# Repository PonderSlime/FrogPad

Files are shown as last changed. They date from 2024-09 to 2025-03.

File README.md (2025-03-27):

# Frogpad
This is my design for Hack Club's Hackpad Challenge. It features a rotary encoder, 15 switches, and a charming froggy face.
<details>
<summary>

# Details
</summary>
<details>

<summary>

## The PCB
</summary>
The first step in my design was to create the pcb schematic.
This involved choosing what components to use and how they should be wired to each other. Overall, this was the easiest step in the design process, since
I am only using 15 switches and 1 rotary encoder.

The next step was for me to decide on a layout for my board.
I decided to go for an erginomic key layout. The encoder sits conveniently in a spot that could be considered a "nose." The macropad truly became a frog when
I decided that I wanted a unique outline and couldn't quite achieve what I was initally going for. During the case design, I was forced to relocate the SeeedStudio
XIAO RP2040 several times, to allow it to plug in better. I also modified the through-hole sizes several times for a similar reason: I needed the case to stay together.

I made many mistakes on the way of my project, and several times had to completely rebuild my case design. Although I encountered many setbacks, 
I still continued on. The hardest thing with designing the pcb was when I was forced to completely restart on the wire traces due to a slight layout change.
frogpad PCB

</details>
<details>
<summary>

## The Case

</summary>
For this step I decided to use Onshape. Since this was my first time using Onshape, this took longer than i had hoped for. Luckily, after learning the basics, it was pretty easy to design my case to fit my board. I'm really happy with how it turned out.
</details>
<details>
<summary>

## The Firmware
</summary>
In the past, i have mainly used python for my hardware projects (the only one to date being for bin.) However, in my mind, this project is more like professional design. Since this was the case, I decided to use a dedicated keyboard firmware tool: QMK. I struggled a lot on this step, since i couldn't immediatly find a good firmware base for the RP2040. In the end, I was able to finish the firmware succesfully, with support for the encoder and all 15 keys.
</details>
<details>
<summary>

## In Retrospect
</summary>

During the time spent designing my macropad, I learned more about how to use Kicad, Onshape and QMK. All of these tools were hard in there own way.

Kicad was difficult for me due to the unique board outline and drill hole sizes.

Onshape was tricky because it was my first time using 3D cad software other than Blender.

OMK was especially difficult due to lack of information on using a RP2040 microcontroller.# PonderSime-Hackpad
</details>

</details>

# Keymaps
### Layer 0
| ______ | Space | TO(2) | ______ | ______ |
| --- | --- | ---  | ---| ---|
| Q | W | E | R | T |
| A | S | D | F | G |
| Z | X | C | V | TD(0) |

### Layer 1
| ______ | Space | TO(2) | ______ | ______ |
| --- | --- | ---  | ---| ---|
| Y | U | I | O | P |
| H | J | K | L | . |
| B | N | M | , |  |

### Layer 2
| ______ | TO(0) | TO(3) | ______ | ______ |
| --- | --- | ---  | ---| ---|
| TD(2) | TD(3) | TD(4) | TD(5) | TD(6) |
| TD(7) | TD(8) | TD(9) | TD(10) | TD(11) |
| Left | Up | Down | Right | TD(1) |

### Layer 3
| ______ | TO(2) | Space | ______ | ______ |
| --- | --- | ---  | ---| ---|
| F1 | F2 | F3 | F4 | F5 |
| F6 | F7 | F8 | F9 | F10 |
| F11 | F12 | Esc | Tab |  |

## Tap-Dance Info
| Which One | On Tap | On Hold | Double Tap | Tap and Hold |
| --- | --- | --- | --- | --- |
| 0 | Space | MO(1) | Enter | Bksp | 
| 1 | Space | MO(3) | Enter | Bksp | 
| 2 | 1 |  | 6 |  | 
| 3 | 2 |  | 7 |  | 
| 4 | 3 |  | 8 |  | 
| 5 | 4 |  | 9 |  | 
| 6 | 5 |  | 0 |  | 
| 7 | - |  | = |  | 
| 8 | ' |  | ` |  | 
| 9 | [ |  | ] |  | 
| 10 | Esc |  | / |  | 
| 11 | \ |  | Caps |  |

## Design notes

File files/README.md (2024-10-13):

# Frogpad

# BOM:
- 15x Cherry MX switches (through hole)
- 15x 0805 (2012 metric) 1.5x1.40mm HandSolder Diodes (whatever one has specs closest to 1n4148 diodes)
- 1x Alps Alpine EC11E Switch Encoder
- 1x PCB
- 1x SeeedStudio XIAO RP2040 microcontroller

# 3D Prints
- 1x Case Top
- 1x Case Bottom
- 1x Rotary encoder cap (scaling is wrong for some reason, i dont need a massive encoder cap!)

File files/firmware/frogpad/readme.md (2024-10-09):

# frogpad

frogpad

*A short description of the keyboard/project*

* Keyboard Maintainer: [PonderSlime](https://github.com/PonderSlime)
* Hardware Supported: *The PCBs, controllers supported*
* Hardware Availability: *Links to where you can find this hardware*

Make example for this keyboard (after setting up your build environment):

    make frogpad:default

Flashing example for this keyboard:

    make frogpad:default:flash

See the [build environment setup](https://docs.qmk.fm/#/getting_started_build_tools) and the [make instructions](https://docs.qmk.fm/#/getting_started_make_guide) for more information. Brand new to QMK? Start with our [Complete Newbs Guide](https://docs.qmk.fm/#/newbs).

## Bootloader

Enter the bootloader in 3 ways:

* **Bootmagic reset**: Hold down the key at (0,0) in the matrix (usually the top left key or Escape) and plug in the keyboard
* **Physical reset button**: Briefly press the button on the back of the PCB - some may have pads you must short instead
* **Keycode in layout**: Press the key mapped to `QK_BOOT` if it is available

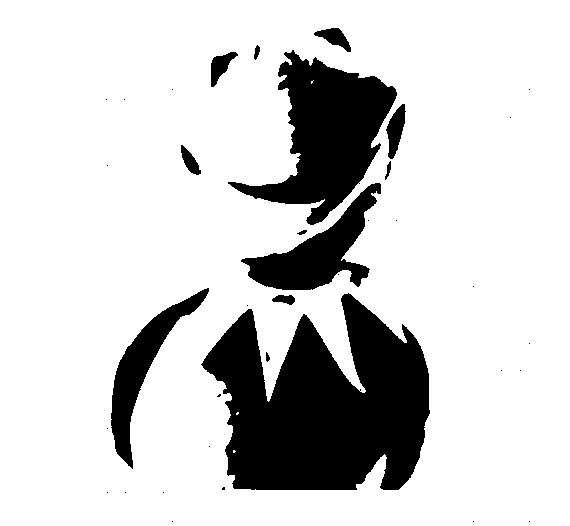
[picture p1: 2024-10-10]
files/pcb/decoration/kermit_sihlouette.png

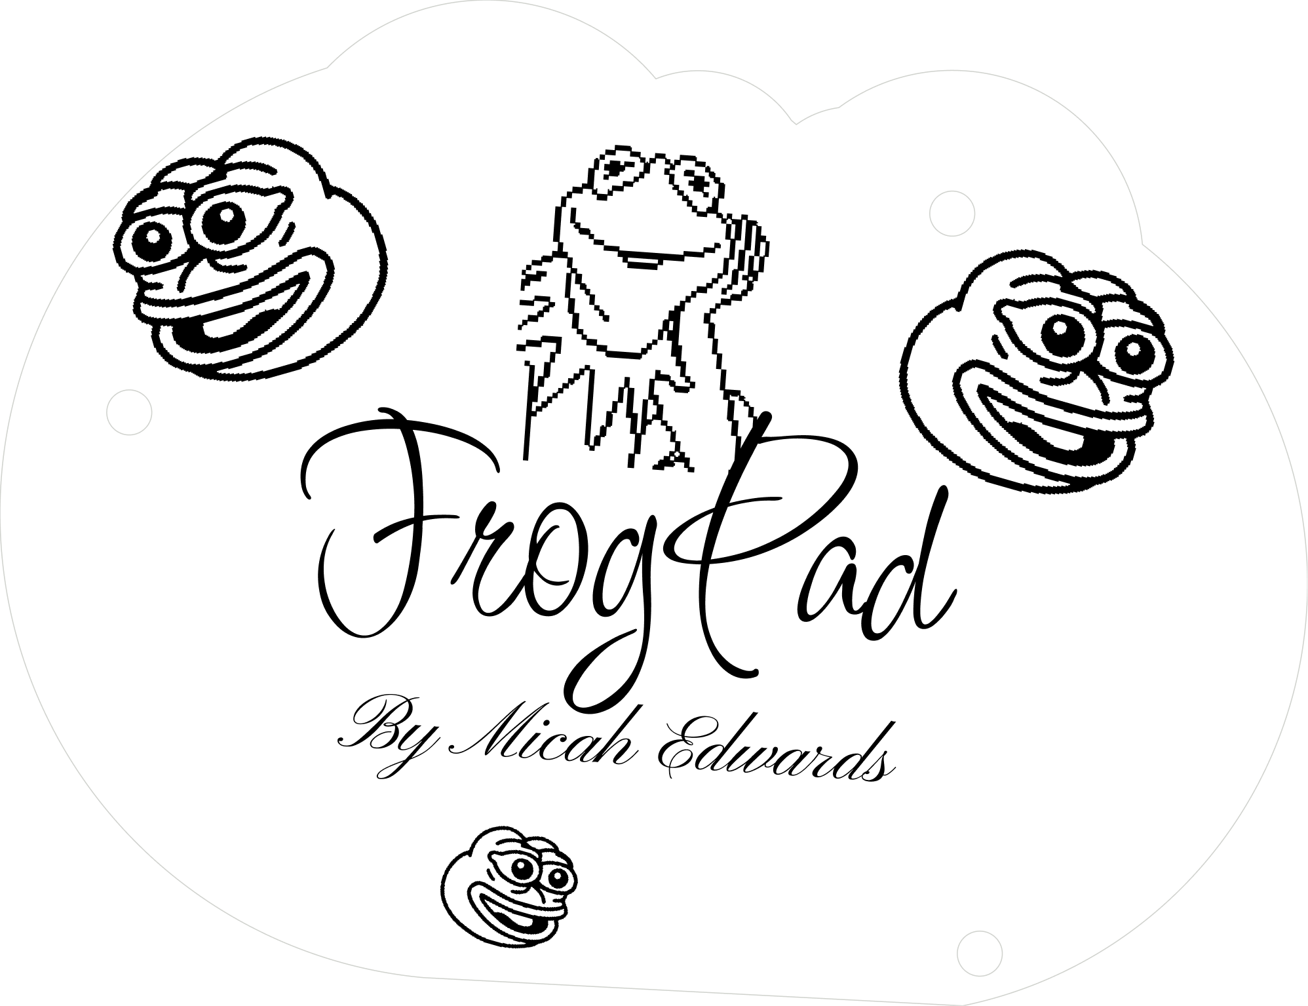
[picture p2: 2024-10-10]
files/pcb/decoration/Back.png

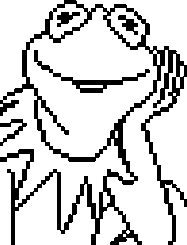
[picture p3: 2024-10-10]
files/pcb/decoration/kermit.png

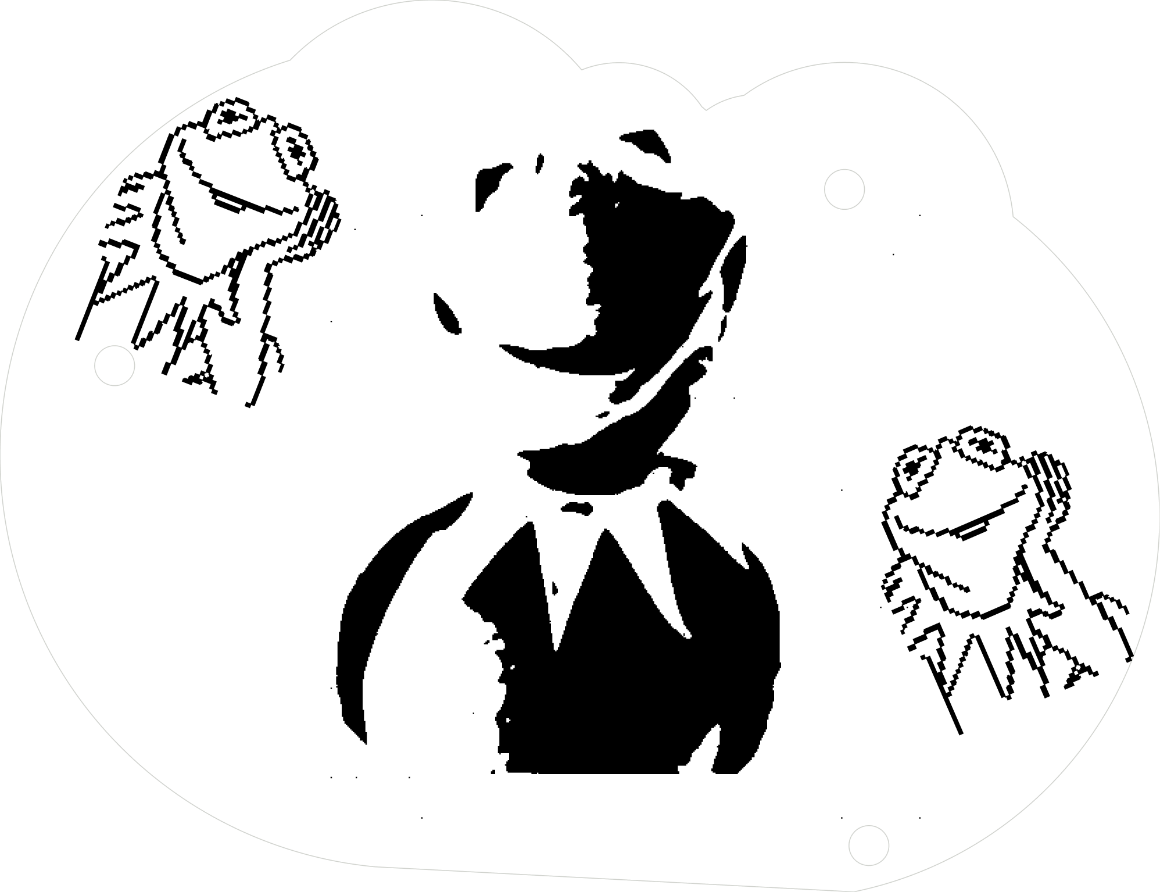
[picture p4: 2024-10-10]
files/pcb/decoration/Front.png

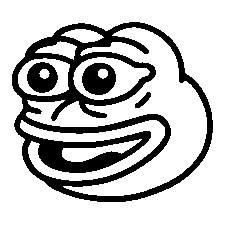
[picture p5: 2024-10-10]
files/pcb/decoration/Pepe.png

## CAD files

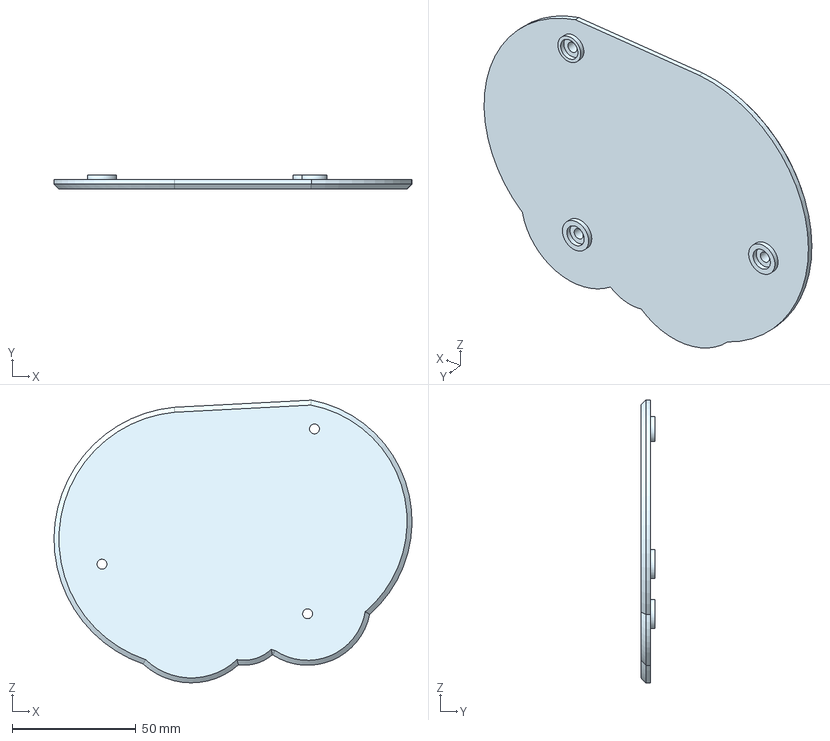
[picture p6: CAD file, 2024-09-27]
files/cad/3D Printed Parts/3D Printed Parts - Bottom Case Lid.step
144.7 x 5.80 x 114.2 mm

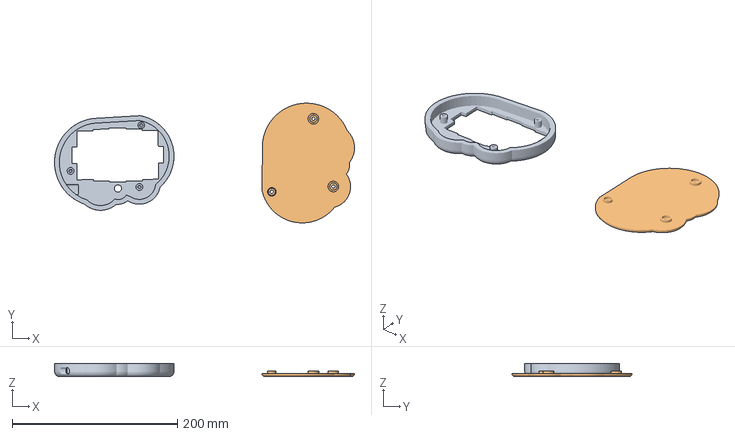
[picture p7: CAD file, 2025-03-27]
files/cad/Fixed 3D Models/Case - Bottom Case Lid.3mf
363.0 x 144.9 x 16.0 mm
Case - Case Top.stl
Case - Bottom Case Lid.stl

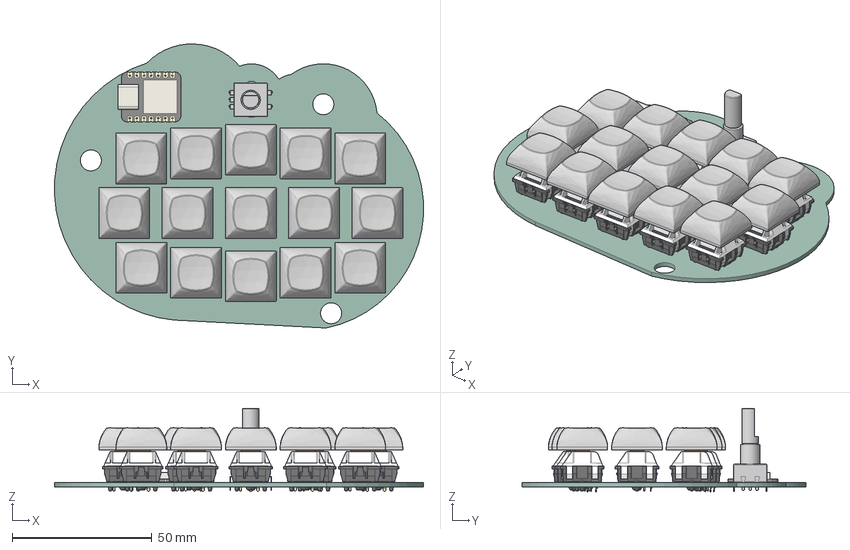
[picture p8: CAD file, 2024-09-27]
files/cad/hackpad_pcb_reference.step
131.9 x 101.5 x 29.8 mm
SW_Cherry_MX_PCB x 15
DSA V4 1x1 v4 x 15
Seeeduino Xiao v2
(Unsaved)
my_hackpad_PCB

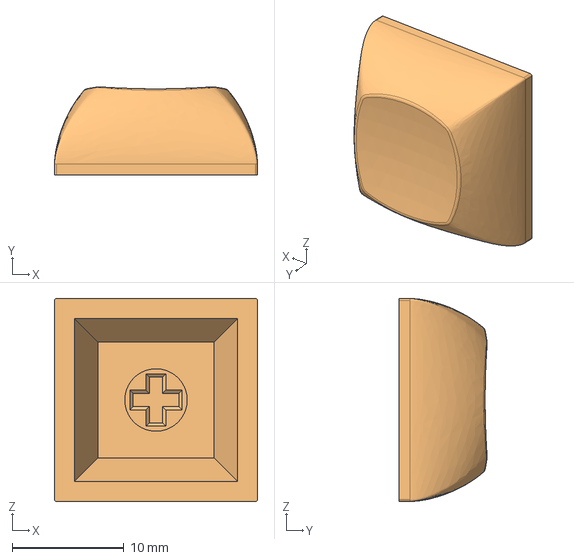
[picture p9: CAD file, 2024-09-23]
files/pcb/models/DSA 1u.step
18.2 x 7.91 x 18.2 mm

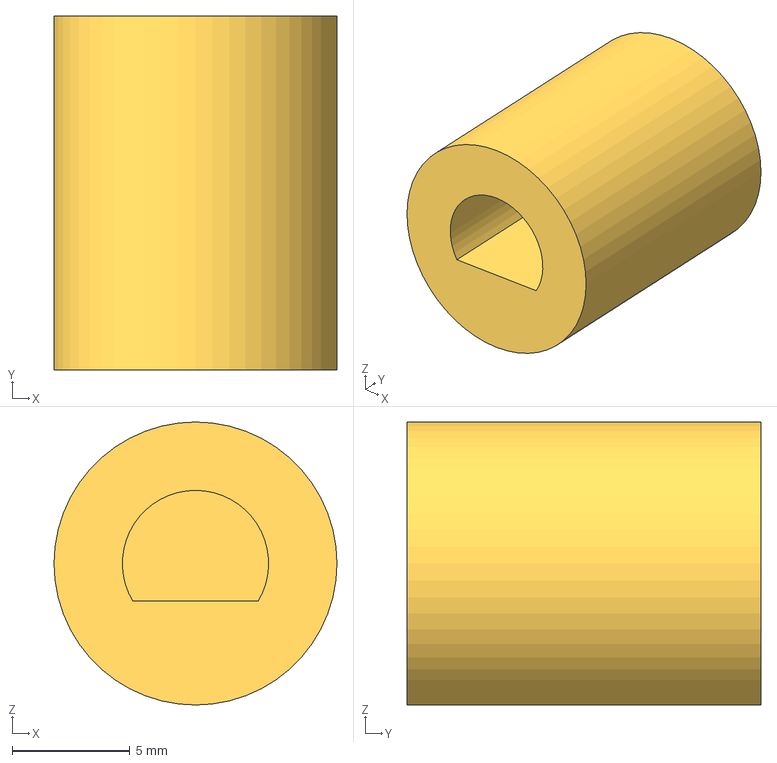
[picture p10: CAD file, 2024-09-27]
files/cad/3D Printed Parts/3D Printed Parts - Rotary Dial.step
12.0 x 15.0 x 12.0 mm

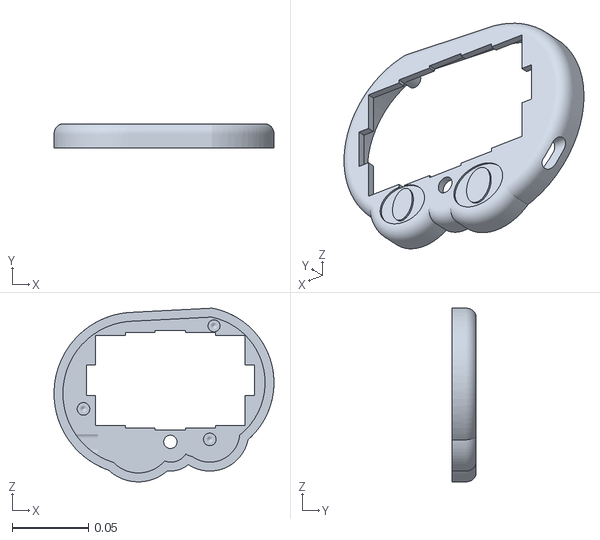
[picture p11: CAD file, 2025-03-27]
files/cad/Fixed 3D Models/Case - Case Top.stl
0.145 x 0.016 x 0.114

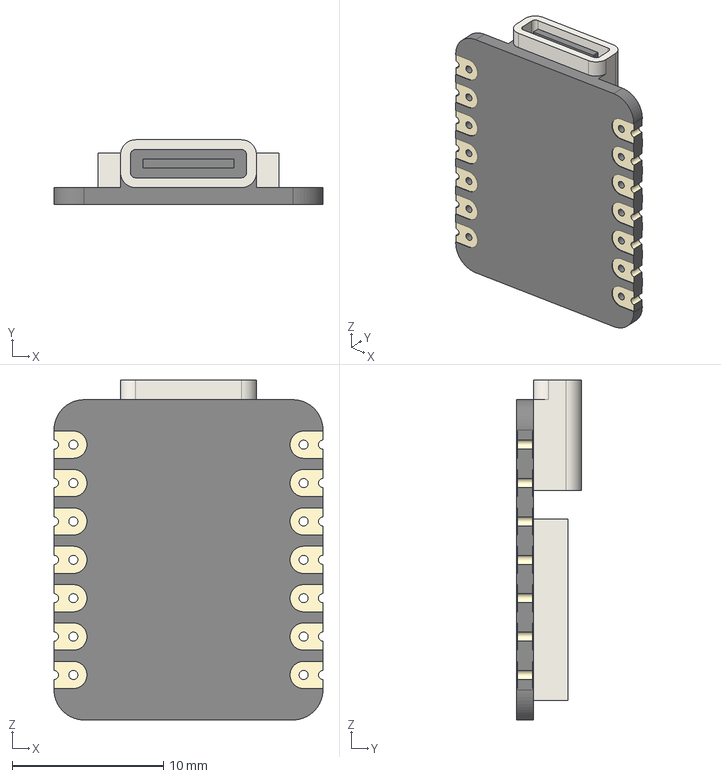
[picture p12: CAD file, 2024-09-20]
files/pcb/models/Seeeduino_Xiao.step
17.8 x 4.27 x 22.5 mm

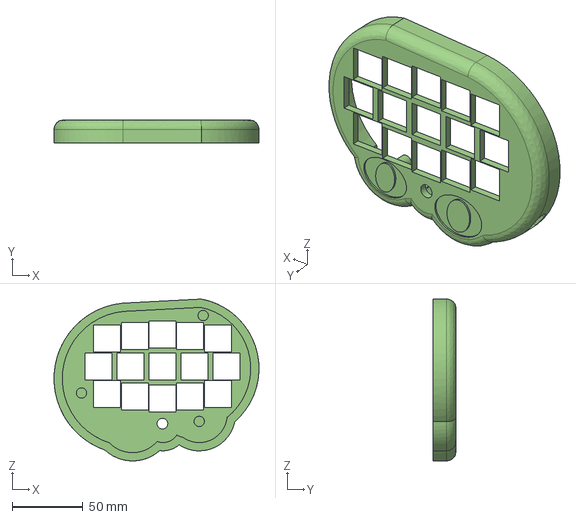
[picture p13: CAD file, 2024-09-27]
files/cad/3D Printed Parts/3D Printed Parts - Case Top.step
144.7 x 16.0 x 114.2 mm

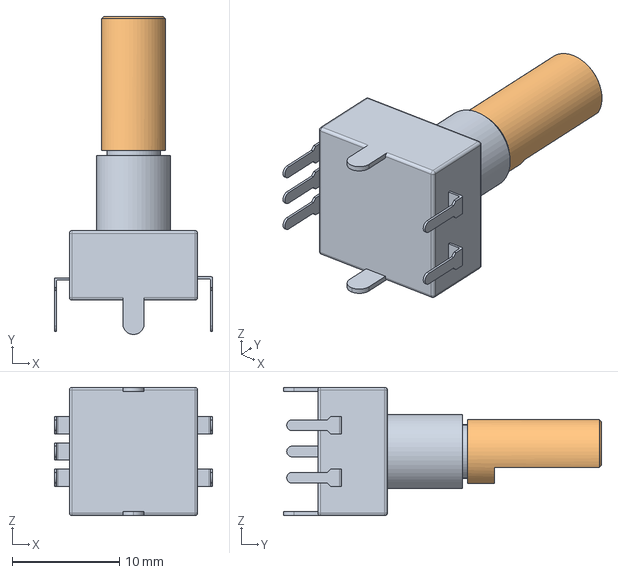
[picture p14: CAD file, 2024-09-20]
files/pcb/models/Rotary Encoder.step
14.8 x 29.7 x 12.0 mm

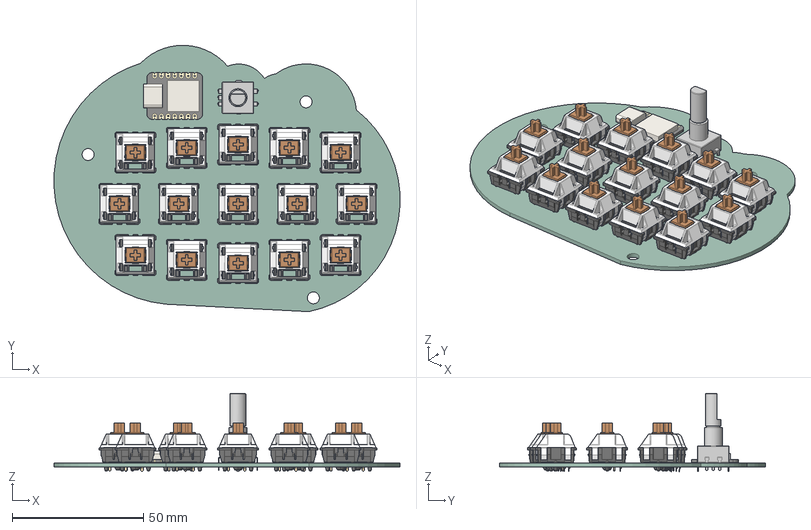
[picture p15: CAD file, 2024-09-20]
files/pcb/models/frogpad.step
131.9 x 101.5 x 29.8 mm
SW_Cherry_MX_PCB x 15
Seeeduino Xiao v2
(Unsaved)
my_hackpad_PCB

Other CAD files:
files/cad/my_hackpad.step
files/cad/3D Printed Parts/3D Printed Parts - Bottom Case Lid.stl
files/cad/3D Printed Parts/3D Printed Parts - Case Top.stl
files/cad/3D Printed Parts/3D Printed Parts - Rotary Dial.stl
files/cad/Fixed 3D Models/Case - Bottom Case Lid.stl

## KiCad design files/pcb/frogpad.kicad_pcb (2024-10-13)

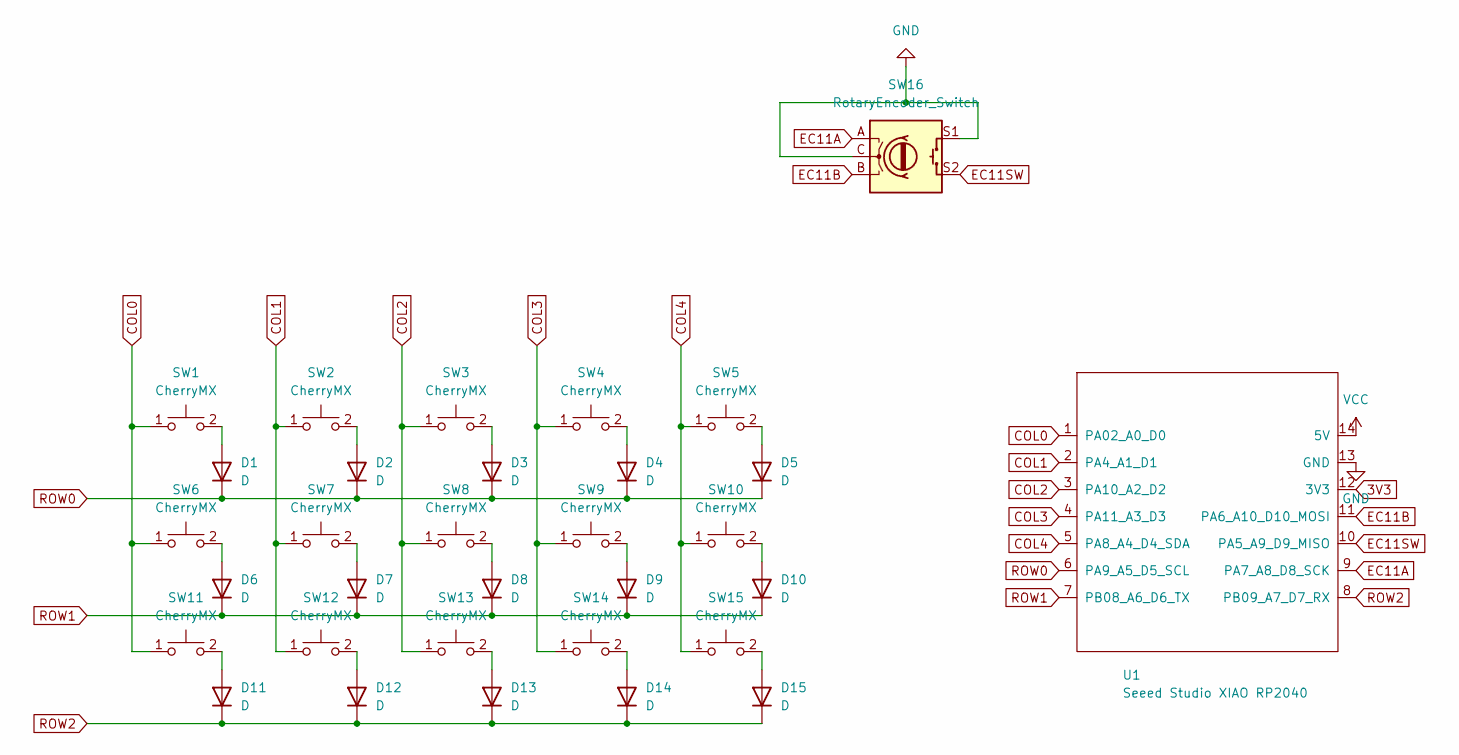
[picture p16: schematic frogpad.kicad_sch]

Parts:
D1, D2, D3, D4, D5, D6, D7, D8, D9, D10, D11, D12, D13, D14, D15: D; D_0805_2012Metric_Pad1.15x1.40mm_HandSolder
SW1, SW2, SW3, SW4, SW5, SW6, SW7, SW8, SW9, SW10, SW11, SW12, SW13, SW14, SW15: CherryMX; SW_Cherry_MX_PCB_1.00u
SW16: RotaryEncoder_Switch; RotaryEncoder_Alps_EC11E-Switch_Vertical_H20mm
U1: Seeed Studio XIAO RP2040; XIAO-Generic-Thruhole-14P-2.54-21X17.8MM

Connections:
3V3: U1.12 (3V3)
COL0: SW1.1, SW6.1, SW11.1, U1.1 (PA02_A0_D0)
COL1: SW2.1, SW7.1, SW12.1, U1.2 (PA4_A1_D1)
COL2: SW3.1, SW8.1, SW13.1, U1.3 (PA10_A2_D2)
COL3: SW4.1, SW9.1, SW14.1, U1.4 (PA11_A3_D3)
COL4: SW5.1, SW10.1, SW15.1, U1.5 (PA8_A4_D4_SDA)
EC11A: SW16.A, U1.9 (PA7_A8_D8_SCK)
EC11B: SW16.B, U1.11 (PA6_A10_D10_MOSI)
EC11SW: SW16.S2, U1.10 (PA5_A9_D9_MISO)
GND: SW16.C, SW16.S1, U1.13 (GND)
unnamed: D1.2 (A), SW1.2
unnamed: D2.2 (A), SW2.2
unnamed: D3.2 (A), SW3.2
unnamed: D4.2 (A), SW4.2
unnamed: D5.2 (A), SW5.2
unnamed: D6.2 (A), SW6.2
unnamed: D7.2 (A), SW7.2
unnamed: D8.2 (A), SW8.2
unnamed: D9.2 (A), SW9.2
unnamed: D10.2 (A), SW10.2
unnamed: D11.2 (A), SW11.2
unnamed: D12.2 (A), SW12.2
unnamed: D13.2 (A), SW13.2
unnamed: D14.2 (A), SW14.2
unnamed: D15.2 (A), SW15.2
ROW0: D1.1 (K), D2.1 (K), D3.1 (K), D4.1 (K), D5.1 (K), U1.6 (PA9_A5_D5_SCL)
ROW1: D6.1 (K), D7.1 (K), D8.1 (K), D9.1 (K), D10.1 (K), U1.7 (PB08_A6_D6_TX)
ROW2: D11.1 (K), D12.1 (K), D13.1 (K), D14.1 (K), D15.1 (K), U1.8 (PB09_A7_D7_RX)
VCC: U1.14 (5V)

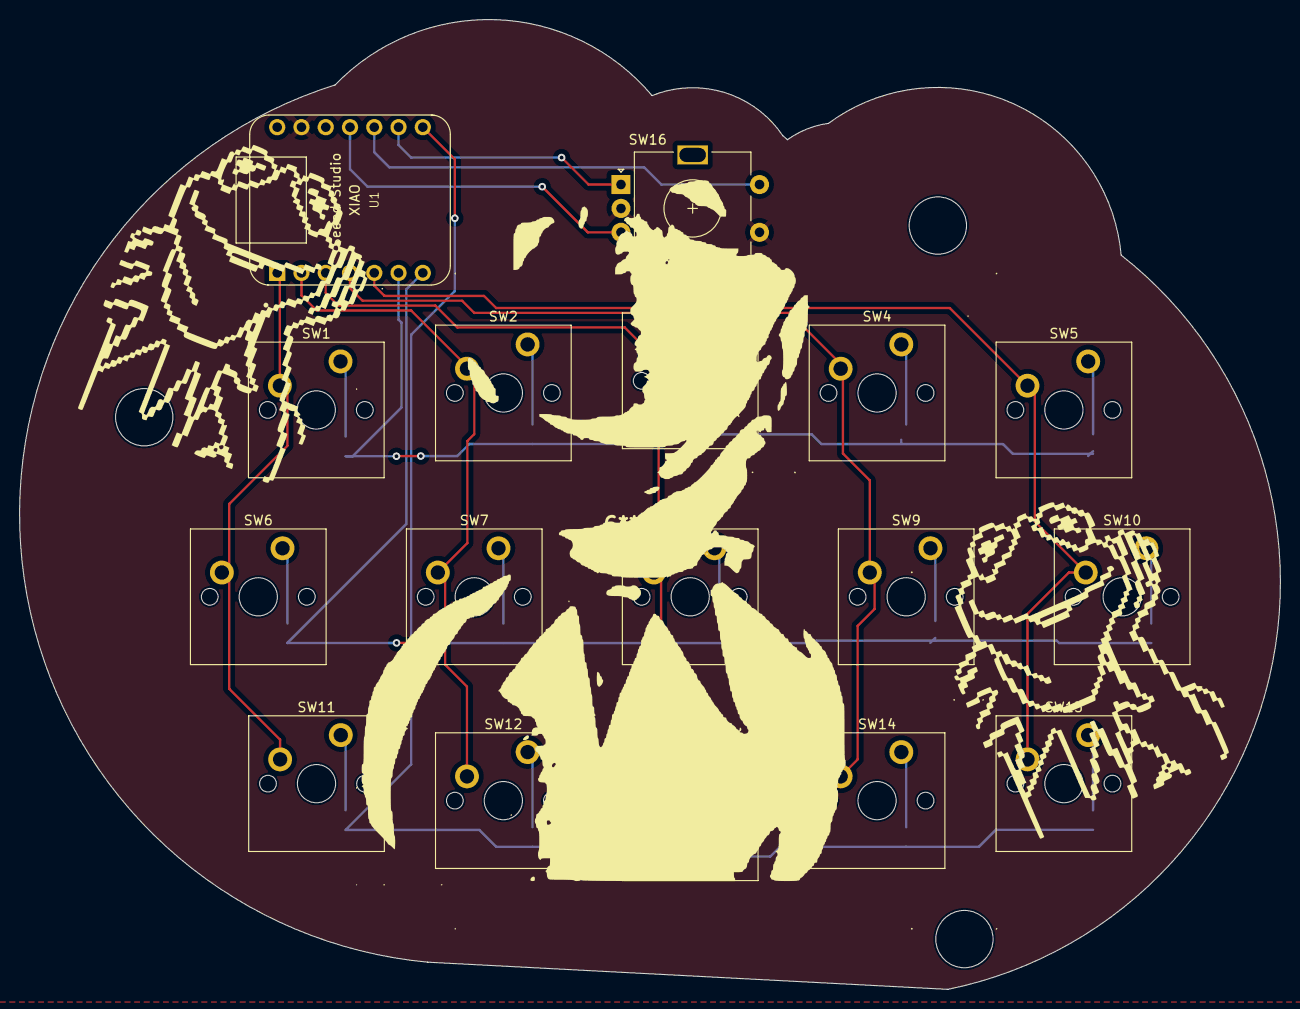
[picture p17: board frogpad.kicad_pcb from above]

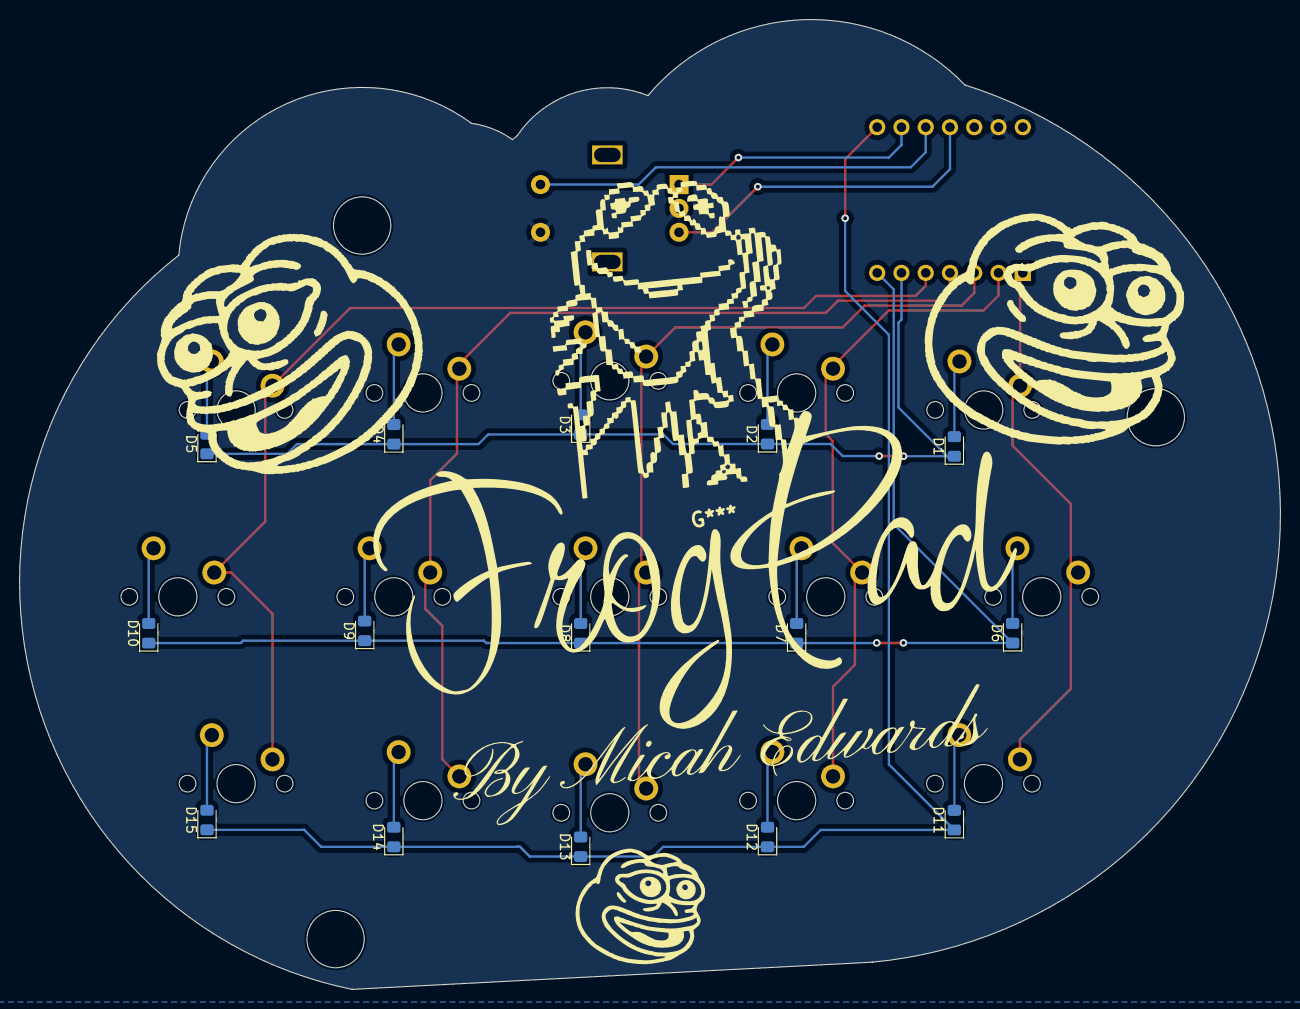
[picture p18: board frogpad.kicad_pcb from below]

Board: 2 copper layers, 132.0 x 101.5 mm, 32 parts (15 on the bottom side), 27 nets.

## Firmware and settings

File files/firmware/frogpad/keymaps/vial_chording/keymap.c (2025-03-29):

/* Copyright 2024 Micah Edwards
 *
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
 * You should have received a copy of the GNU General Public License
 * along with this program.  If not, see <http://www.gnu.org/licenses/>.
 */
#include QMK_KEYBOARD_H

void process_combo_event(uint16_t combo_index, bool pressed) {
    if (!pressed) {
        switch(combo_index) {
            
        }
    }
};

/* bool process_record_user(uint16_t keycode, keyrecord_t *record) {
    if (record->event.pressed) {
        // Do nothing on press
        return false; // Skip further processing of this key
    } else {
        // Send keycode on release
        register_code(keycode);
        unregister_code(keycode);
        return false; // Skip further processing of this key
    }
} */

const uint16_t PROGMEM keymaps[][MATRIX_ROWS][MATRIX_COLS] = {
    [0] = LAYOUT(
        KC_A, KC_B,   KC_C,   KC_D,   KC_E, \
        KC_F, KC_G,   KC_H,   KC_I,   KC_J,  \
        KC_K, KC_L,   KC_M,   KC_N,   KC_O
    ),
    [1] = LAYOUT(
        KC_S, KC_I,   KC_G,   KC_M,   KC_A, \
        KC_TRNS, KC_TRNS,   KC_TRNS,   KC_TRNS,   KC_TRNS,  \
        KC_TRNS, KC_TRNS,   KC_TRNS,   KC_TRNS,   AC_TOGG
    ),
    [2] = LAYOUT(
        KC_TRNS, KC_TRNS,   KC_TRNS,   KC_TRNS,   KC_TRNS, \
        KC_TRNS, KC_TRNS,   KC_TRNS,   KC_TRNS,   KC_TRNS,  \
        KC_TRNS, KC_TRNS,   KC_TRNS,   KC_TRNS,   KC_TRNS
    ),
    [3] = LAYOUT(
        KC_TRNS, KC_TRNS,   KC_TRNS,   KC_TRNS,   KC_TRNS, \
        KC_TRNS, KC_TRNS,   KC_TRNS,   KC_TRNS,   KC_TRNS,  \
        KC_TRNS, KC_TRNS,   KC_TRNS,   KC_TRNS,   KC_TRNS
    )
};

#if defined(ENCODER_MAP_ENABLE)
const uint16_t PROGMEM encoder_map[][NUM_ENCODERS][NUM_DIRECTIONS] = {
    [0] = { ENCODER_CCW_CW(MS_WHLU, MS_WHLD) },
    [1] = { ENCODER_CCW_CW(MS_WHLU, MS_WHLD) },
    [2] = { ENCODER_CCW_CW(MS_WHLU, MS_WHLD) },
    [3] = { ENCODER_CCW_CW(MS_WHLU, MS_WHLD) }
};
#endif

#if defined(DIP_SWITCH_MAP_ENABLE)
const uint16_t PROGMEM dip_switch_map[NUM_DIP_SWITCHES][NUM_DIP_STATES] = {
    DIP_SWITCH_OFF_ON(TO(0), TO(1)),
};
#endif

/*
void matrix_init_user(void) {

}

void matrix_scan_user(void) {

}

bool led_update_user(led_t led_state) {
    return true;
}
*/

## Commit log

2024-09-12 KiCad Project started
    [my_hackpad.kicad_pcb, my_hackpad.kicad_sch]
2024-09-15 Libraries added, schematic done
    [my_hackpad.kicad_pcb, my_hackpad.kicad_sch]
2024-09-16 Key layout finished, wire routing started
    [my_hackpad.kicad_pcb, my_hackpad.kicad_sch]
2024-09-20 Libraries added, case design started, PCB routing complete
    [Case - PonderPad.step, Rotary Encoder.step, Seeeduino_Xiao.step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]
2024-09-23 PCB Finished
    [Case - PonderPad.step, DSA 1u.step, my_hackpad.kicad_pcb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]
2024-09-27 Case updated
    [3D Printed Parts - Bottom Case Lid.step, 3D Printed Parts - Case Top.step, 3D Printed Parts - Rotary Dial.step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]
2024-10-09 Case added, GND plane fixed
    [3D Printed Parts - Bottom Case Lid.stl, 3D Printed Parts - Case Top.stl, 3D Printed Parts - Rotary Dial.stl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]
2024-10-09 Actual gnd plane fixed
    [my_hackpad.kicad_pcb]
2024-10-10 PCB wire traces updated
    [my_hackpad.kicad_pcb]
2024-10-10 Through holes fixed
    [my_hackpad.kicad_pcb]
2024-10-10 Case updated, through holes fixed
    [3D Printed Parts - Bottom Case Lid.stl, 3D Printed Parts - Case Top.stl, my_hackpad.kicad_pcb]
2024-10-12 Files reorganized, backups removed
    [DSA 1u.step, Rotary Encoder.step, Seeeduino_Xiao.step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]
2024-10-13 gbr files added
    [frogpad-B_Cu.gbr, frogpad-B_Mask.gbr, frogpad-B_Paste.gbr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]
2025-03-27 Ig i can't ignore stuff...
    [3D Printed Parts - Bottom Case Lid.step, 3D Printed Parts - Bottom Case Lid.stl, 3D Printed Parts - Case Top.step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]
2025-03-28 Added missing firmware stuff
    [keymap.c]

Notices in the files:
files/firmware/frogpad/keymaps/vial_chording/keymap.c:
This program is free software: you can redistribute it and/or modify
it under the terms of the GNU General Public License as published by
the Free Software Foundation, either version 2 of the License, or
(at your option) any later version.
